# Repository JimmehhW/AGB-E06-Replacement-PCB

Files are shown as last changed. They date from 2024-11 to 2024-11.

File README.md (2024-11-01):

# [Read the License!](LICENSE.txt)
# AGB-E06-Replacement-PCB
Replacement PCB for damaged gameboy advance games using the AGB-E06 pcb
## Credits
Thanks to HDR for the symbols and footprints for the board outline, cart bus, mask rom, battery pads and a few ground pads.  
His repo can be found [here](https://github.com/HDR/NintendoPCBs).
### General Info
Please note this PCB can only be used as a replacement board for an original game.  
  
Order at 0.8mm and with ENIG, **NOT HASL**.  
### SRAM vs FRAM
***As a quick note, if your donor board has a working SRAM I would generally reccomend you simply use that and not go out of your way to get a new FRAM chip since a battery save will likely last more than long enough for most people.***  
  
  This board works with both the original save chip (SRAM) OR a replacement new part, a FM18W08 (FRAM) with the benefit of the FRAM being that a battery is not required to maintain the save. If FRAM is used, do not install a battery and instead populate R5 with a 10k ohm resistor (sized for 0603), this goes between pins 20 and 28 of the FM18W08 to act as a pullup resistor since the functionality of its chip enable pin is inverted compared to the original SRAM.  
  As a side note, the SRAM/FRAM footprint on the board is sized for the FM18W08 which is slightly smaller than the original SRAM, although I haven't had any trouble getting the original SRAM on. 
### BOM 
|Designator|Component|
|---|---|
|C1,C2,C3,C4,C6|0402 0.1uF|
|C5|0603 ?|
|R1|0402 1k|
|R2,R4|0402 100k|
|R3|0402 5k|
|R5|0603 10k (FRAM ONLY!)|
|BT1|CR1616 Tabbed|
|U1|harvested (MX23L6406-12C)|
|U2|harvested (BS62LV256SC-70) OR FM18W08|
|U3|harvested (BU9803F)|
|U4|harvested (PST3425)|
  
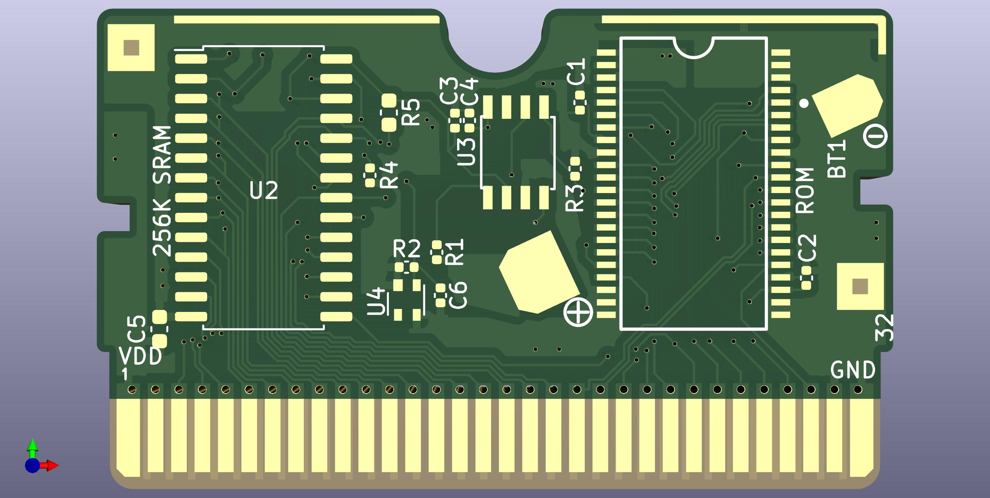
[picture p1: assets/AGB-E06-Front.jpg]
FRONT

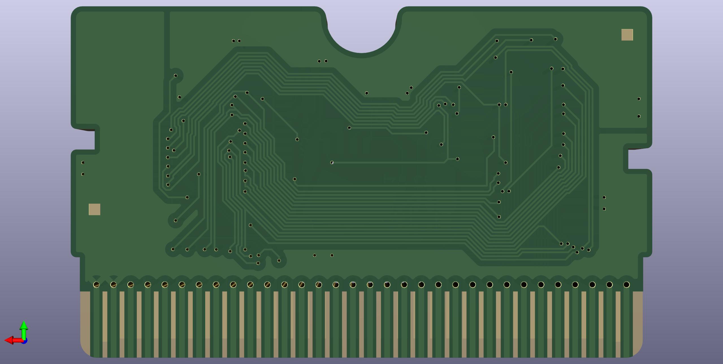
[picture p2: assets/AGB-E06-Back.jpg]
BACK


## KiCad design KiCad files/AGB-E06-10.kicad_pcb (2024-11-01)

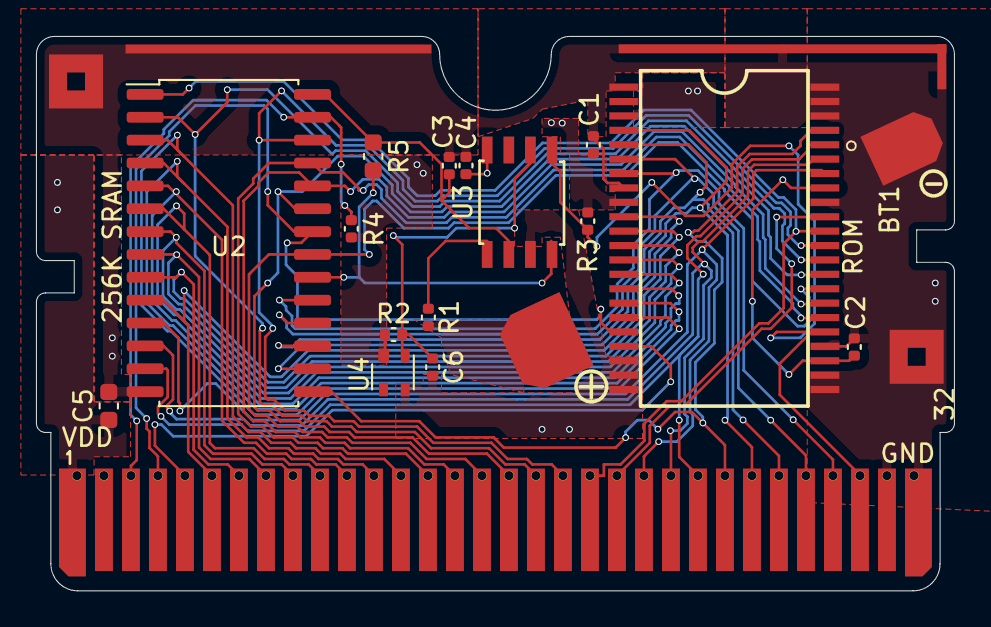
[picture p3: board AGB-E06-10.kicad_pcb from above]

Board: 2 copper layers, 51.0 x 30.8 mm, 21 parts (0 on the bottom side), 35 nets.

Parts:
A2, A3: 3x3Pad; 3x3mm_Pad
A6: CartBrow_Left; AGB-Cartbrow_Left
A7: CartBrow_Right; AGB-Cartbrow_Right
BT1: CR1616; AGB-CR1616
C1: 127nF; C_0402_1005Metric
C2: 116nF; C_0402_1005Metric
C3: 130nF; C_0402_1005Metric
C4: 113nF; C_0402_1005Metric
C5: ??; C_0603_1608Metric
C6: 122nF; C_0402_1005Metric
R1: 1k; C_0402_1005Metric
R2, R4: 100k; C_0402_1005Metric
R3: 5k; C_0402_1005Metric
R5: 10k; C_0603_1608Metric
U0: CartBus; AGB_Cartridge
U1: MX23L12806-12C; AGB-TSOP-II-44_10.16x18.41mm_P0.8mm
U2: FM18W08-SG; SOIC-28W_7.5x17.9mm_P1.27mm
U3: TSSOP-8_3x3mm_P0.65mm
U4: PST4325

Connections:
+3V3: C1.1, C2.1, C4.1, C5.1, R2.1, R3.1, R4.1, U0.1 (VCC), U1.3 (VCC), U1.9 (VCC), U1.25 (VCC), U1.37 (VCC), U3.8 (Vcc), U4.2 (Vcc)
A0: U0.6 (A0), U1.10 (A0), U2.10 (A0)
A1: U0.7 (A1), U1.11 (A1), U2.9 (A1)
A2: U0.8 (A2), U1.12 (A2), U2.8 (A2)
A3: U0.9 (A3), U1.13 (A3), U2.7 (A3)
A4: U0.10 (A4), U1.14 (A4), U2.6 (A4)
A5: U0.11 (A5), U1.15 (A5), U2.5 (A5)
A6: U0.12 (A6), U1.16 (A6), U2.4 (A6)
A7: U0.13 (A7), U1.17 (A7), U2.3 (A7)
A8: U0.14 (A8), U1.28 (A8), U2.25 (A8)
A9: U0.15 (A9), U1.29 (A9), U2.24 (A9)
A10: U0.16 (A10), U1.30 (A10), U2.21 (A10)
A11: U0.17 (A11), U1.31 (A11), U2.23 (A11)
A12: U0.18 (A12), U1.32 (A12), U2.2 (A12)
A13: U0.19 (A13), U1.33 (A13), U2.26 (A13)
A14: U0.20 (A14), U1.34 (A14), U2.1 (A14)
A15: U0.21 (A15), U1.35 (A15)
CS: U0.5 (CS), U1.19 (CS)
CS2: R3.2, U0.30 (RST), U1.27 (CS2), U3.5 (CS2)
D0: U0.22 (D0), U1.38 (D0), U2.11 (DQ0)
D1: U0.23 (D1), U1.39 (D1), U2.12 (DQ1)
D2: U0.24 (D2), U1.40 (D2), U2.13 (DQ2)
D3: U0.25 (D3), U1.41 (D3), U2.15 (DQ3)
D4: U0.26 (D4), U1.4 (D4), U2.16 (DQ4)
D5: U0.27 (D5), U1.5 (D5), U2.17 (DQ5)
D6: U0.28 (D6), U1.6 (D6), U2.18 (DQ6)
D7: U0.29 (D7), U1.7 (D7), U2.19 (DQ7)
GND: A2.1, A3.1, A6.1, A7.1, BT1.2 (-), C1.2, C2.2, C3.2, C4.2, C5.2, C6.2, U0.31 (SND), U0.32 (GND), U1.1 (GND), U1.8 (GND), U1.20 (GND), U1.21 (GND), U1.22 (GND), U1.23 (GND), U1.24 (GND), U1.26 (GND), U1.36 (GND), U1.42 (GND), U1.43 (GND), U1.44 (GND), U2.14 (VSS), U3.3 (GND), U4.4 (Vss)
unnamed: BT1.1 (+), R1.2
unnamed: R1.1, U3.1 (Vss)
unnamed: C3.1, R5.1, U2.28 (VDD), U3.2 (Vout)
unnamed: R5.2, U2.20 (~CE), U3.4 (CE)
unnamed: C6.1, R2.2, U3.6 (Vss), U4.1 (Vout)
RD: U0.4 (RD), U1.18 (RD), U2.22 (~OE)
WR: R4.2, U0.3 (WR), U2.27 (~WE)
